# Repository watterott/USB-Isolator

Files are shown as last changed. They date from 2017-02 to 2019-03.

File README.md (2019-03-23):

# USB-Isolator
USB port isolator based on an Analog Devices ADuM3160 to protect computers against over-voltage spikes, ESD pulses and to avoid ground loops.

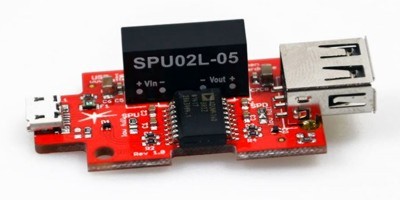
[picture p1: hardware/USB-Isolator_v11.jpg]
USB-Isolator


* [Analog Devices ADuM3160](https://www.analog.com/en/products/adum3160.html) USB Digital Isolator 
* USB 2.0 compatible
* Full Speed (12 Mbps, default setting) and Low Speed (1.5 Mbps) switchable via soldering Jumper (typical low speed devices are keyboards, mice)
* Built-in DC-DC converter (up to 400mA output current on Host side)
* Upstream short-circuit protection
* USB-Device: microUSB
* USB-Host: USB-A
* Open-Source and released under the [Creative Commons Attribution Share-Alike License](https://creativecommons.org/licenses/by-sa/4.0/).
* **[Documentation on learn.watterott.com](https://learn.watterott.com)**

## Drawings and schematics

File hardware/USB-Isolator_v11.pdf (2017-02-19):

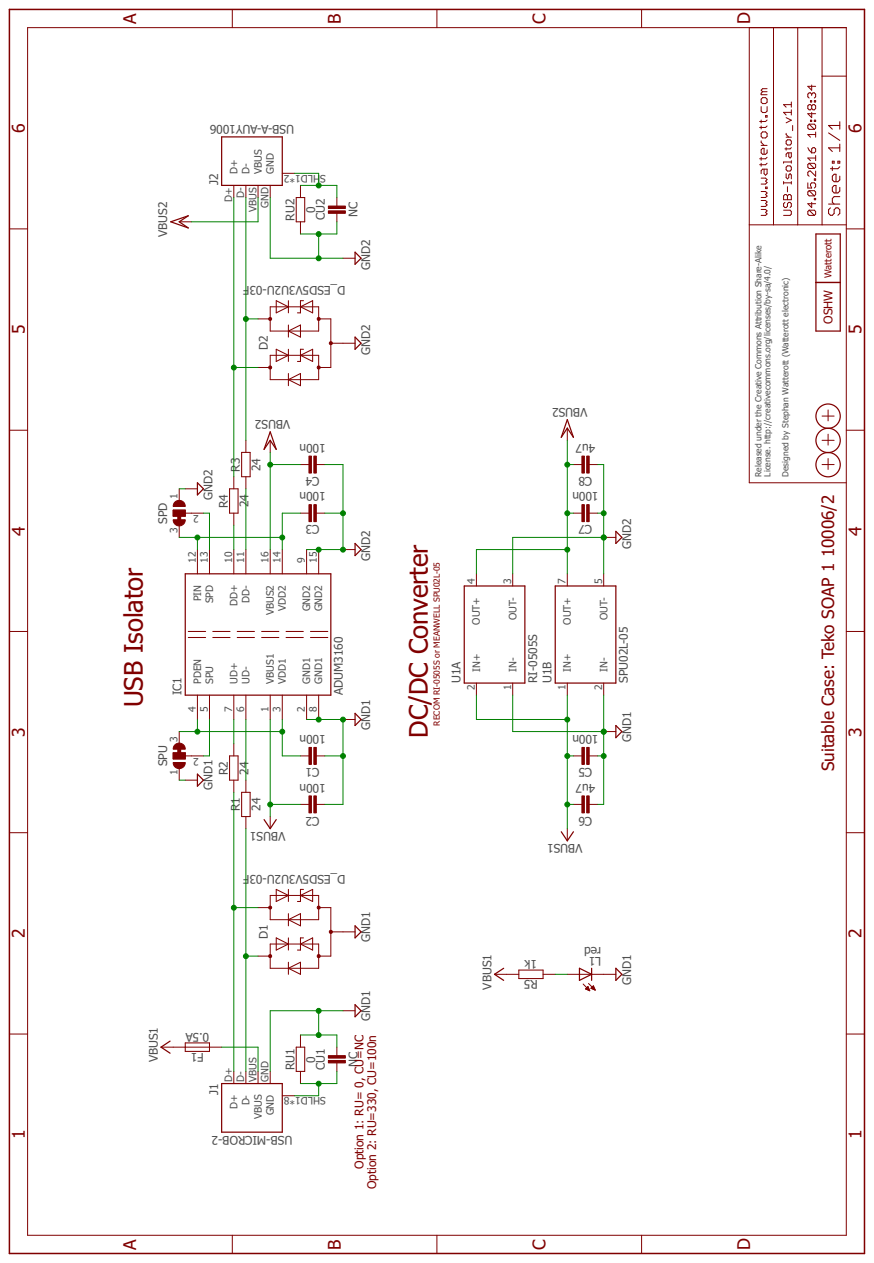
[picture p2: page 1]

GND1 GND1 GND2 GND2 n001 n001 n001 n001 n001 n001 7u4 7u4 24 24 24 24 der k1 GND1 ADUM3160 GND1 GND2 2SUBV 1SUBV A5. 0 VBUS1 VBUS2 1SUBV 2SUBV VBUS1 RI-0505S SPU02L-05 NC0 NC0 GND1 GND2 F30- U2U3V5DSE_D GND1 F30- U2U3V5DSE_D GND2 Released under the Creative Commons At ribution Share-Alike License. ht p://creativecommons.org/licenses/by-sa/4.0/ Designed by Stephan Wat erot (Wat erot electronic) D+ D+ D- D- VBUS VBUS GND GND J1 2- BORCI M- BSU8*1DL HS 1C2C3C4C 5C7C6C8C R1 R2 R3 R4 D+ D+ D- D- VBUS VBUS GND GND J2 6001YUA- A- BSU2*1DL HS 1L 5R IC1PDEN 4 VDD1 3 GND1 2 VBUS1 1 SPU 5 UD- 6 UD+ 7 GND1 8 GND2 15 DD+ 10 DD- 11 PIN 12 SPD 13 VDD2 14 GND2 9 VBUS2 16 SPU 3 1 2 SPD 3 1 21F IN+ 2 IN- 1 OUT+ 4 OUT- 3 U1AIN+ 1 IN- 2 OUT+ 7 OUT- 5 U1B CU1 RU1 CU2 RU2 D1 D2 Suitable Case: Teko SOAP 1 10006/2 DC/DC Converter USB Isolator Option 1: RU= 0, CU=NC Option 2: RU=330, CU=100n RECOM RI-0505S or MEANWELL SPU02L-05 ABCD 1 2 3 4 5 6 ABCD 1 2 3 4 5 6 OSHW Watterott

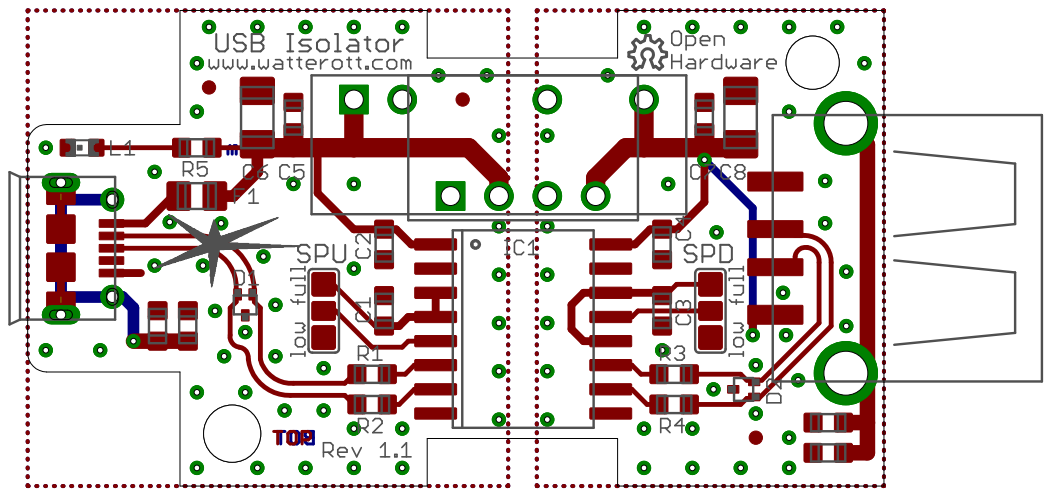
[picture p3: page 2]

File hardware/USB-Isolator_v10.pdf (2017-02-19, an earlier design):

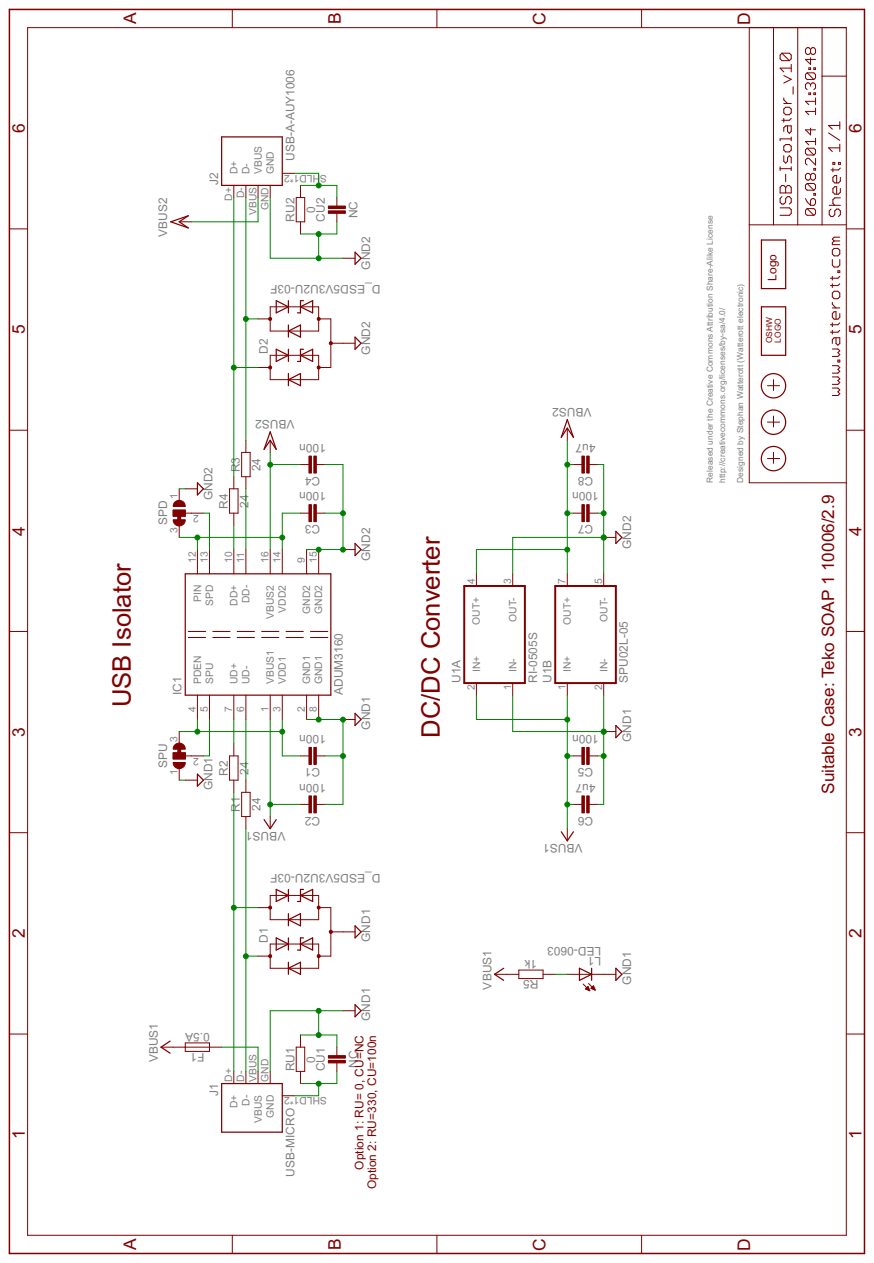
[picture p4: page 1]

GND1 GND1 GND2 GND2 n001 n001 n001 n001 n001 n001 7u4 7u4 24 24 24 24 3060- DEL k1 GND1 ADUM3160 GND1 GND2 2SUBV 1SUBV A5. 0 VBUS1 VBUS2 1SUBV 2SUBV VBUS1 RI-0505S SPU02L-05 N0C N0C GND1 GND2 F30- U2U3V5DSE_DGND1 F30- U2U3V5DSE_DGND2 Released under the Creative Commons Attribution Share-Alike License http://creativecommons.org/licenses/by-sa/4.0/ Designed by Stephan Watterott (Watterott electronic) D+ D+ D- D- VBUS VBUS GND GND J1 USB-MICRO 2* 1DLHS 1C2C3C4C 5C7C6C8C R1 R2 R3 R4 D+ D+ D- D- VBUS VBUS GND GNDJ2 USB-A-AUY1006 2* 1DLHS 1L 5R IC1PDEN 4 VDD1 3 GND1 2 VBUS1 1 SPU 5 UD- 6 UD+ 7 GND1 8 GND2 15 DD+ 10 DD- 11 PIN 12 SPD 13 VDD2 14 GND2 9 VBUS2 16 SPU3 1 2 SPD 3 1 21F IN+ 2 IN- 1 OUT+ 4 OUT- 3 U1AIN+ 1 IN- 2 OUT+ 7 OUT- 5 U1B CU1 RU1 CU2 RU2 D1 D2 Suitable Case: Teko SOAP 1 10006/2.9 DC/DC Converter USB Isolator Option 1: RU= 0, CU=NC Option 2: RU=330, CU=100n ABCD 1 2 3 4 5 6 ABCD 1 2 3 4 5 6 OSHW LOGO Logo

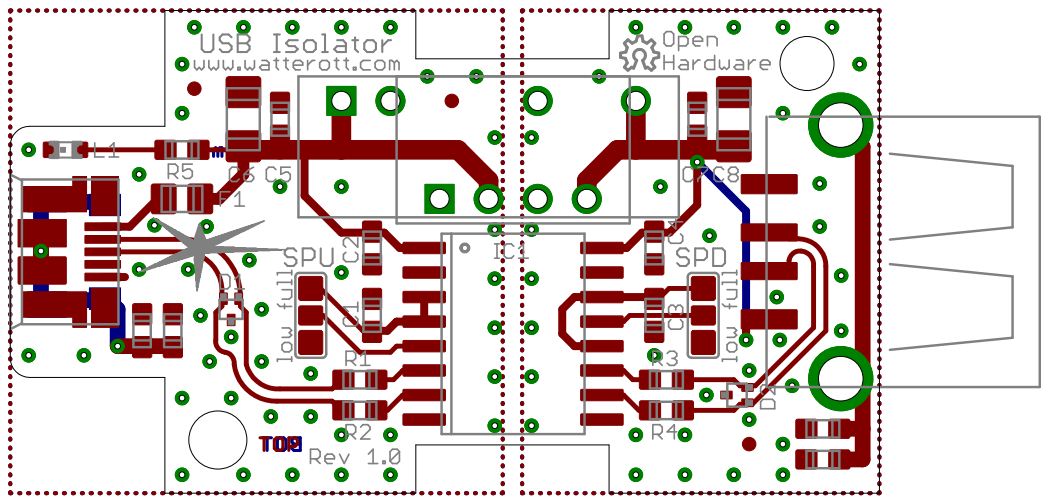
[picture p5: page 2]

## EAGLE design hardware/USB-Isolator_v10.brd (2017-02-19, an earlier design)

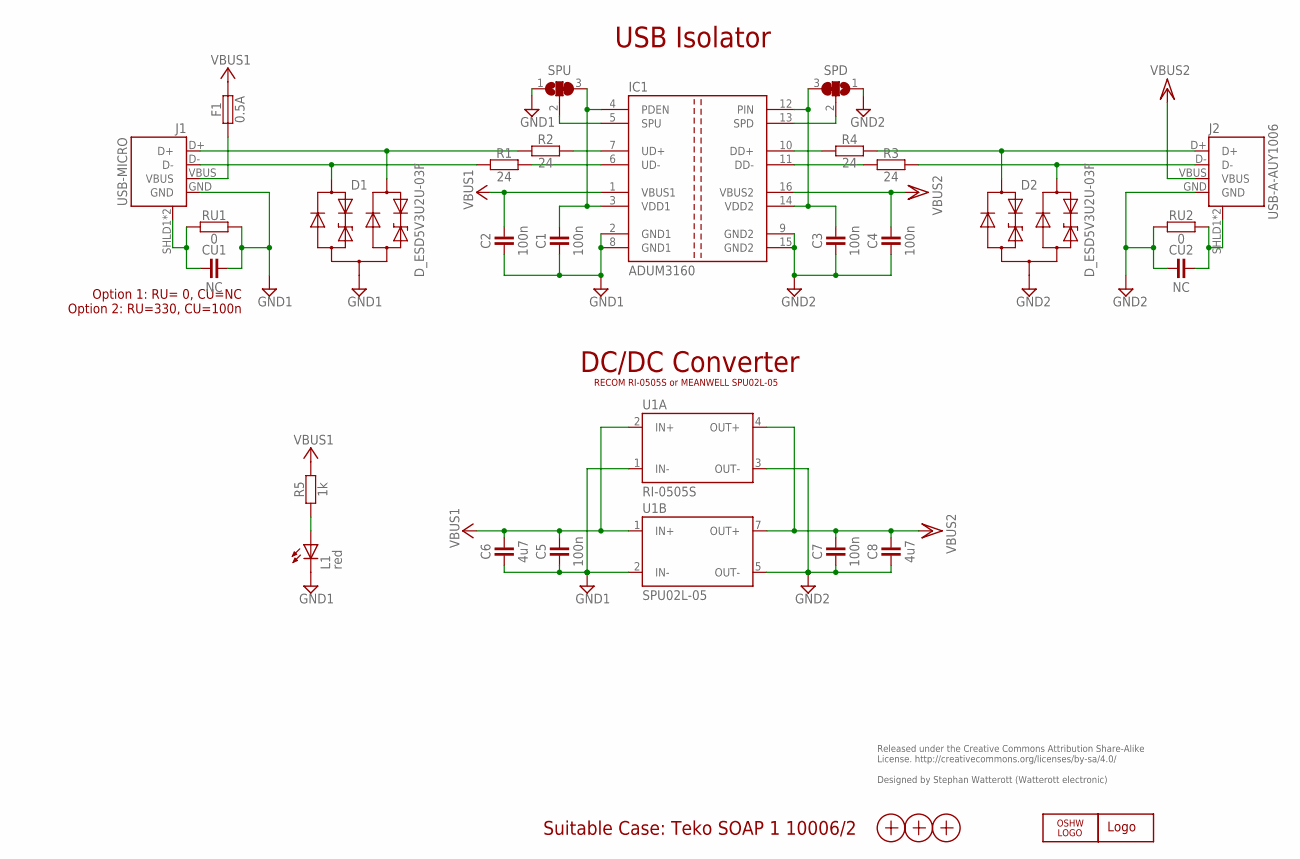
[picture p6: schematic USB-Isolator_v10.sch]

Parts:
C1, C2, C3, C4, C5, C7: 100n; R0603
C6, C8: 4u7; R1206
CU1, CU2: NC; R0603
D1, D2: D_ESD5V3U2U-03F; TSFP3
F1: 0.5A; R0805
IC1: ADUM3160; SO16W
J1: USB-MICRO; USB-MICRO-10103594
J2: USB-A-AUY1006; USB-AU-Y1006-R
L1: red; LED_0603
LOGO2: OSHW_LOGOX0070; OSHW_6X70
LOGO3: LOGO-S_PLACE_M; SPARK_TPLACE_M
R1, R2, R3, R4: 24; R0603
R5: 1k; R0603
RU1, RU2: 0; R0603
SPD: JUMPER3
SPU: JUMPER3
U1A: RI-0505S; RECOM_SIP4_RI
U1B: SPU02L-05; MEANWELL_SIP7_SPU02
X1, X2, X3: PASSER-07; PASSER_07MM

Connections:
D1_N: D1.1 (C1), J1.D-, R1.1
D1_P: D1.2 (C2), J1.D+, R2.1
D2_N: D2.2 (C2), J2.D-, R3.2
D2_P: D2.1 (C1), J2.D+, R4.2
DD+: IC1.10 (DD+), R4.1
DD-: IC1.11 (DD-), R3.1
GND1: C1.1, C2.1, C5.1, C6.1, CU1.2, D1.3 (A), IC1.2 (GND1), IC1.8 (GND1), J1.GND, L1.C, RU1.2, SPU.1, U1A.1 (IN-), U1B.2 (IN-)
GND2: C3.1, C4.1, C7.1, C8.1, CU2.1, D2.3 (A), IC1.9 (GND2), IC1.15 (GND2), J2.GND, RU2.1, SPD.1, U1A.3 (OUT-), U1B.5 (OUT-)
LED: L1.A, R5.1
SHLD1: CU1.1, J1.SHLD1 (SHIELD), J1.SHLD2 (SHIELD), RU1.1
SHLD2: CU2.2, J2.SHLD1 (SHIELD), J2.SHLD2 (SHIELD), RU2.2
SPD: IC1.13 (SPD), SPD.2
SPU: IC1.5 (SPU), SPU.2
UD+: IC1.7 (UD+), R2.2
UD-: IC1.6 (UD-), R1.2
VBUS1: C2.2, C5.2, C6.2, F1.2, IC1.1 (VBUS1), R5.2, U1A.2 (IN+), U1B.1 (IN+)
VBUS1A: F1.1, J1.VBUS
VBUS2: C4.2, C7.2, C8.2, IC1.16 (VBUS2), J2.VBUS, U1A.4 (OUT+), U1B.7 (OUT+)
VDD1: C1.2, IC1.3 (VDD1), IC1.4 (PDEN), SPU.3
VDD2: C3.2, IC1.12 (PIN), IC1.14 (VDD2), SPD.3

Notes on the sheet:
Suitable Case: Teko SOAP 1 10006/2
Released under the Creative Commons Attribution Share-Alike License. http://creativecommons.org/licenses/by-sa/4.0/ Designed by Stephan Watterott (Watterott electronic)
DC/DC Converter
USB Isolator
Option 1: RU= 0, CU=NC Option 2: RU=330, CU=100n
RECOM RI-0505S or MEANWELL SPU02L-05

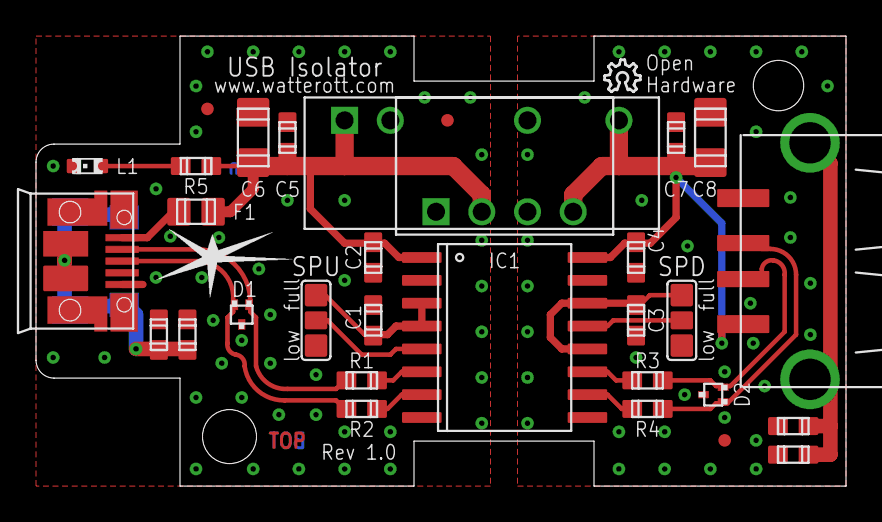
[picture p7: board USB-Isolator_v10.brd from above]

Board: 2 copper layers, 45.0 x 25.0 mm, 33 parts (0 on the bottom side), 20 nets.
